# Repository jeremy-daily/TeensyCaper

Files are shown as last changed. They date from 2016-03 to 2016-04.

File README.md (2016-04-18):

# TeensyCaper
Electronics to interface a PRJC Teensy 3.2 32-bit Arduino Compatible board with J1939 connections in heavy duty equipment. Includes Two CAN Channels, J1708, and LIN.

This repository assumes you know how to work with the <a href="https://www.pjrc.com/store/teensy32.html" target="_blank" >Teensy</a> and <a href="https://www.pjrc.com/teensy/teensyduino.html">Teensyduino.</a>

## Bill of Materials

Reference the Schematic for the Designators. Most items are from <a href="http://www.mouser.com" target="_blank" > Mouser </a> or Sparkfun.

| Comment | Description | Designator | Quantity | Manufacturer | Manufacturer Part Number | Supplier | Supplier Part Number |
| --- | --- | --- | --- | --- | --- | --- | --- |
| CR1225FV-LF | Coin Cell Battery 3V 2-PIN VERT 48mAh 12.5 x 2.5mm | Batt1 | 1 | Renata | CR1225FV-LF | Mouser | 614-CR1225FV-LF| 
| Teensy 3.2 | 32 Bit Arduino-Compatible Microcontroller | BRD1 | 1 | <a target="_blank" href="https://www.pjrc.com/store/teensy32.html">PRJC</a> | TEENSY32 | Sparkfun | DEV-13736| 
| 0.1uF | Multilayer Ceramic Capacitors MLCC - Leaded 50volts 0.1uF 10% X7R | C1, C2, C5, C6 | 4 | AVX | SR215C104KAA | Mouser | 581-SR215C104K| 
| 330 uF | Aluminum Electrolytic Capacitors - Leaded 330uF 35V | C3, C4 | 2 | Panasonic | EEU-FC1V331 | Mouser | 667-EEU-FC1V331| 
| 10uF | Multilayer Ceramic Capacitors MLCC - Leaded 50volts 10uF 10% X7R | C7 | 1 | AVX | SR655C106KAR | Mouser | 581-SR655C106KAR| 
| STPS2150 | DIODE SCHOTTKY 60V 2A AXIAL | D1 | 1 | STMicroelectronics | STPS2150 | Mouser | 511-STPS2150| 
| ESP8266 | Sparkfun ESP8266 Module (WRL-13678) | J1 | 1 | Espressif | ESP8266 | Sparkfun | WRL-13678| 
| 10 Pos Mini-Fit Jr. | Headers & Wire Housings 10 CKT R/A HEADER | J2 | 1 | Molex | 39-30-1100 | Mouser | 538-39-30-1100| 
| Headers | Pin headers for Teensy | BRD1 | 2 | 3M  |  929400-01-28-RK | Mouser |  517-929400-01-28-RK| 
| 2N3904 | NPN General Purpose Amplifier | Q1, Q2 | 2 | Central Semiconductor | 2N3904 | Mouser | 610-2N3904| 
| 4.7k | Metal Film Resistors - Through Hole 4.7K OHM 1/4W 1% | R1, R3, R5, R6, R10, R12 | 6 | Yageo | MFR-25FRF52-4K7 | Mouser | 603-MFR-25FRF52-4K7| 
| 47 | Metal Film Resistors - Through Hole 47 OHM 1/4W 1% | R2, R7, R8 | 3 | Yageo | MFR-25FRF52-47R | Mouser | 603-MFR-25FRF52-47R| 
| 1k | Metal Film Resistors - Through Hole 1K ohm 1/4W 1% | R4, R9 | 2 | Yageo | MFR-25FRF52-1K | Mouser | 603-MFR-25FRF521K| 
| MCP2562 | High-Speed CAN Transceiver, 8-Pin PDIP, Industrial Temperature | U1, U2 | 2 | Microchip Technology | MCP2562-E/P | Mouser | 579-MCP2562-E/P| 
| MCP2515-E/P | Stand-Alone CAN Controller With SPI Interface, 18-Pin PDIP | U3 | 1 | Microchip Technology | MCP2515-E/P | Mouser | 579-MCP2515-E/P| 
| MCP2003-E/P | TXRX LIN BUS BIDIRECT 8DIP | U4 | 1 | Microchip Technology | MCP2003-E/P | Mouser | 579-MCP2003EP| 
| SN65HVD12P | RS-485 Interface IC 3.3V RS485 | U6 | 1 | Texas Instruments | SN65HVD12P | Mouser | 595-SN65HVD12P| 
| LD1086V33 | IC REG LDO 3.3V 1.5A TO220AB | VR1 | 1 | STMicroelectronics | LD1086D2M33TR | Mouser | 511-LD1086D2M33-TR| 
| OKI-78SR | 5V DC/DC Converter (7805 replacement) | VR2 | 1 | Murata Power Solutions | OKI-78SR-5/1.5-W36-C | Mouser | 580-OKI78SR5/1.5W36C | 
| Crystal | Crystals 32.768KHz 12ppm 12.5pF | | 1 | Citizen | CFS206-32.768KEZB-U | Mouser | 695-CFS206-327KEZB-U |

Since this is an open source project, feel free to make substitutions as you see fit. Often an engineer or hobbiest will have other version of the parts available to them. 

The Battery and Crystal are for the real time clock on the Teensy. PRJC also sells an SD card adapter to add "flight data recorder" capabilities.

The external interface is with the a 10 position Molex Mini-Fit Jr. and the Molex part numbers to build interface cables are as follows:
* Mouser Part #: 538-39-01-2100
* Molex Part #: 39-01-2100
* Mouser Part #: 538-39-00-0039
* Molex Part #: 39-00-0039

It is advisable to obtain a pin extraction tool for Mini-fit Jr. contacts as well: 
* Mouser Part #: 538-11-03-0044
* Molex Part #: 11-03-0044
Crimpers are also available, but they are expensive (~$250):
* Mouser Part #: 538-63819-0900
* Molex Part #: 63819-0900

The printed circuit board can be ordered from OSH Park in batches of 3 using the following link:



OSH Park sells the Teensy 3.2 too!

### Teensy Headers
The following headers work well with firm inserting force. These are stackable and work for all the expansions boards for the Teensy. They have a long solder tail.
  Mouser Part #: 575-31143164
  Manufacturer Part #:311-43-164-41-001000
  Manufacturer:Mill-Max
  Description: IC & Component Sockets 64 POS STRAIGHT .1"

Additionally, the Mill-Max 310 series is for a base layer (they have standard solder tails).

The following part are dual ended pins that interface with the 311 and 310 series sockets. 
  Mouser Part #: 575-35040132000010
  Manufacturer Part #: 350-40-132-00-001000
  Manufacturer: Mill-Max
  Description: Headers & Wire Housings 32P HDRSTRIP .025Pin .018 SOLDER TAIL
  
## Interface Cables
This section describes some different interface cables than can be made to interface the teensy caper to the networks.
### J1939 at 250k
The black SAE Standard 9-pin connector has the following connections:

| SAE Pin | Description | Suggested Colors | TeensyCaper Pin |
| --- | --- | --- | --- |
| A | Ground | Black | J2:1
| B | Raw Battery + | Red | J2:2
| C | J1939 H | Yellow | J2:3 |
| D | J1939 L | Green | J2:4 |
| E | Shield  | Not used | Not used |
| F | J1708 H | Pink | J2:6 |
| G | J1708 L | Purple | J2:7 |
| H | CAN2 H | White | J2:8 |
| J | CAN2 L | Blue | J2:9 |

Sometimes SAE Pin E can be used for LIN or K-line communications.

The TeensyCaper molex Pin J2:5 is LIN and the pin J2:10 is an open collector that can be switched to ground.

### J1939 Y Splitter Cable
To build a splitter cable, the machined sockets that are used in the diagnostic connector are doubled up. This is not a manuracture approved method of splitting a cable, but it works quite well. 

The parts list is as follows:

|  Description |  Quantity | Manufacturer | Manufacturer Part Number | Supplier | Supplier Part Number |
|  ---|  --- | --- | --- | --- | --- |
| 9-pin Diagnostic Plug Housing | 1 | Amphenol Sine Systems | AHD16-9-1939S | Mouser | 654-AHD16-9-1939S |
| 16 gauge Socket Connector | 9 | Amphenol Sine Systems | AT62-201-16141 | Mouser | 654-AT62-201-16141 |
| 9-pin Inline Receptical | 2 | Amphenol Sine Systems | AHD14-9-1939P | Mouser | 654-AHD14-9-1939P |
| 16 gauge Pin Connector | 18 | Amphenol Sine Systems | AT60-202-16141 | Mouser | 654-AT60-202-16141 |

You will need 18 wires, preferably 2 each of different colors. The wires can be cut to about 8 inches. The side that gets doubled up, it is suggested to strip the ends about 1/2 inch. The other ends get stripped about 1/4 inch. Uing automotive grade 20 gauge wire with TXL or GXL insulation is recommended. Allied Wire and Cable can sell rolls of it; for example, <a target="_blank" href="http://www.awcwire.com/part.aspx?partname=txl-20">TXL-20</a>.

These part numbers also corrospond to Deutsch part numbers by changing the A to a D.

### Man-in-the-Middle Cable
This cable connects to one J1939 connector with a plug housing on CAN1 of the TeensyCaper and another receptical housing to J1939 on CAN2.
The CAN 2 cavities are not used on the 9-pin connector. Power, ground, and J1708 are doubled up on the plug housing. 

## SD Card
### 

Add the following lines to the beginning of the setup() function:
 
  pinMode(SDCS, OUTPUT);
  digitalWrite(SDCS, HIGH);   // de-select the SD Card

  where SDCS is the chip select pin for the SD card.
  
  The SD Card holder from PJRC will not work with the CAN because it uses Pin 4. Therefore, you must cut the pin 4 off the SD card holder and connect it somewhere else, like pin A1.

##Arduino
1. Download Teensyduino with FlexCAN
2. Install library for SD cards from https://github.com/greiman/SdFat-beta

#Software Operations
The philosophy of this setup is to run different operations by using different example sketches. 

##Formatting the SD Card
With an SD card installed in the SD card expansion shield for Teensy ()

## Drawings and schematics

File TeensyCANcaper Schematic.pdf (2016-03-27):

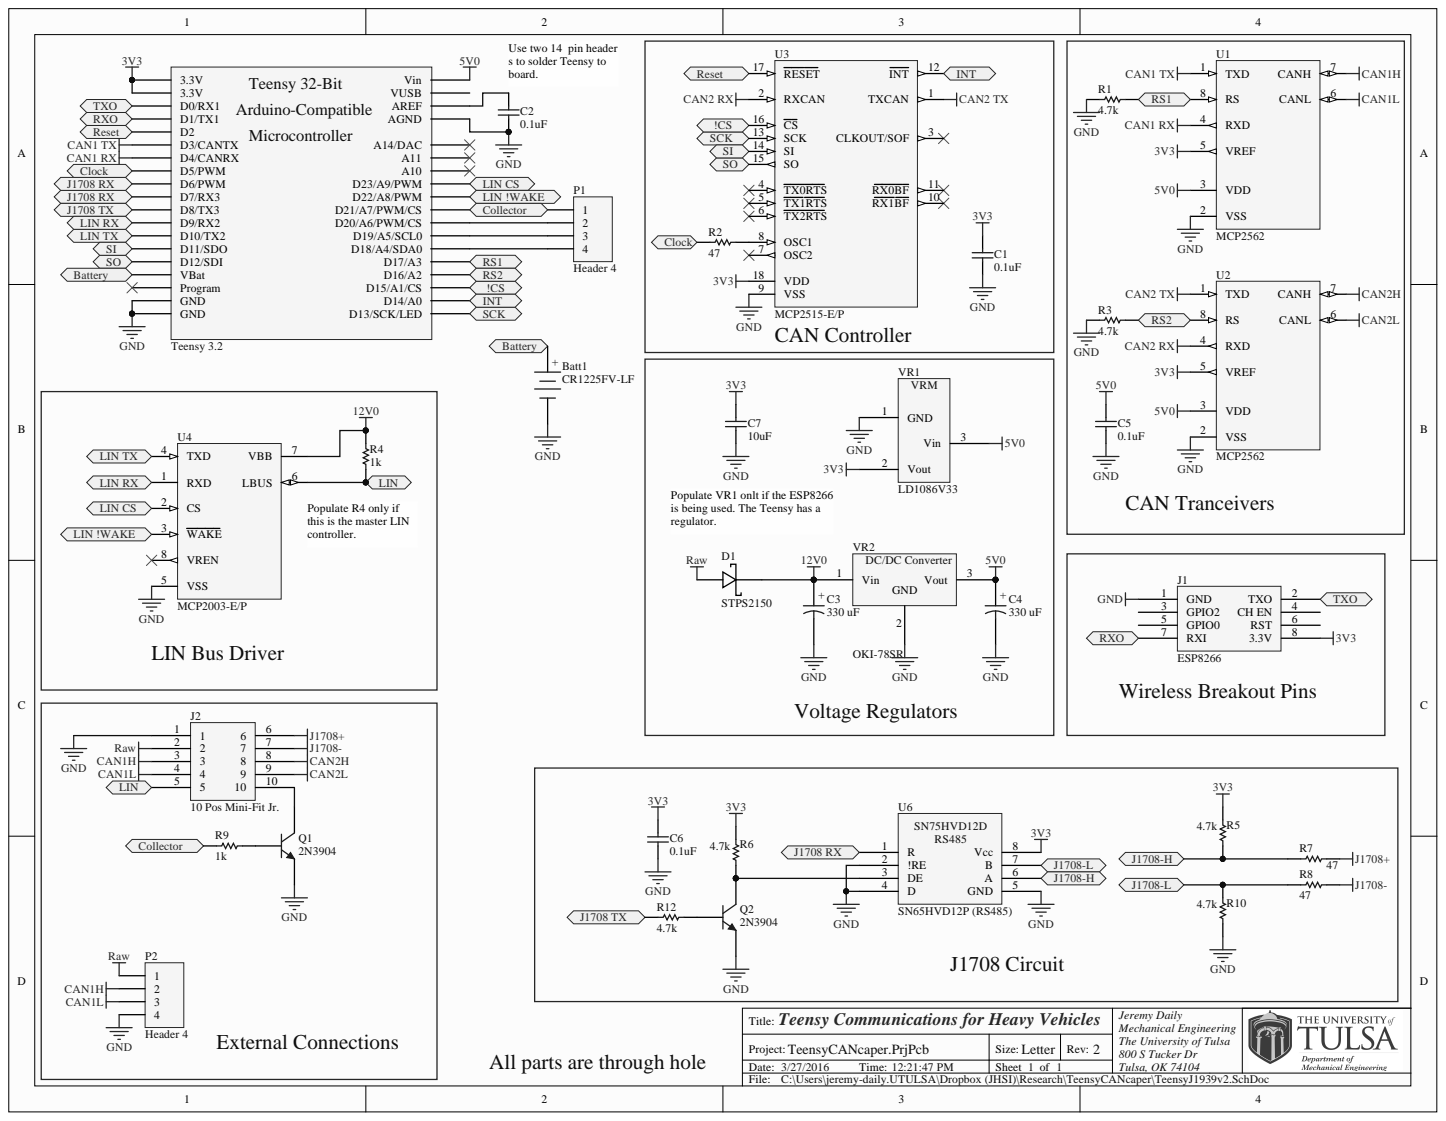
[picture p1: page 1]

Use two 14 pin header
s to solder Teensy to
board.

Populate R4 only if
this is the master LIN
controller.

Populate VR1 onlt if the ESP8266
is being used. The Teensy has a
regulator.

10 Pos Mini-Fit Jr.

Teensy Communications for Heavy Vehicles
Title:

Jeremy Daily
Mechanical Engineering
The University of Tulsa
800 S Tucker Dr

C:\Users\jeremy-daily.UTULSA\Dropbox (JHSI)\Research\TeensyCANcaper\TeensyJ1939v2.SchDoc

All parts are through hole

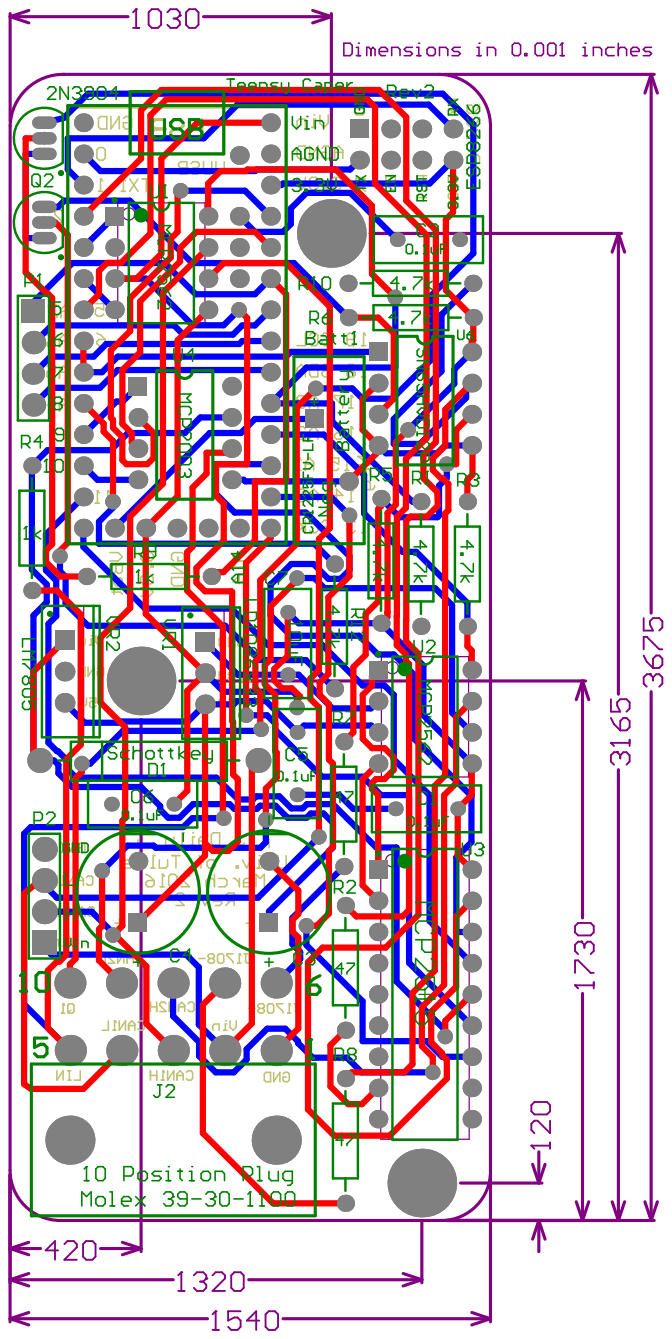
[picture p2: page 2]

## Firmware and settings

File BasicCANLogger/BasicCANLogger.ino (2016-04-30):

/* Getting Started with the J1939 Teensy Caper
Written By Jeremy Daily
17 April 2016

This System is written for a Teensy3.2 with an SD board and the TeensyJ1939Caper 
Needs to cut pin4 from the SD card

Description: A Basic CAN logger

*/

#include <SPI.h>
#include "SdFat.h"
//#include "FreeStack.h"

#include <FlexCAN.h>

// SD chip select pin.  Be sure to disable any other SPI devices such as Enet.
const uint8_t SDchipSelect = 10;
const uint8_t CANchipSelect = A1;

// Log file base name.  Must be six characters or less.
#define CANFILE_BASE_NAME "CANlog"
#define J1708FILE_BASE_NAME "J1708log"

// global for card size
uint32_t cardSize;

const int CANRate = 250000;

FlexCAN CANbus(CANRate);

static CAN_message_t txCANmsg,rxCANmsg;

uint32_t txCANcount,rxCANcount;
uint32_t txCANtimer,rxCANtimer;
uint32_t currentMillis,previousMillis;
boolean recording = true;

// File system object.
SdFat sd;

// Log file.
SdFile CANfile;


// Time in micros for next data record.
uint32_t logTime;

// Write data header.
void writeHeader() {
  CANfile.println(F("CAN Data Log"));
  CANfile.print(F("Rate,"));
  CANfile.println(CANRate, DEC);
  CANfile.print(F("Network,"));
  CANfile.print(F("Micros,"));
  CANfile.print(F("Line,"));
  CANfile.print(F("ID,"));
  CANfile.print(F("DLC,"));
  CANfile.print(F("B0,"));
  CANfile.print(F("B1,"));
  CANfile.print(F("B2,"));
  CANfile.print(F("B3,"));
  CANfile.print(F("B4,"));
  CANfile.print(F("B5,"));
  CANfile.print(F("B6,"));
  CANfile.print(F("B7,"));
  CANfile.println();
}
void logCANframe(){
  uint32_t currentMicros = micros();
  CANfile.print("CAN");
  CANfile.print(",");
  CANfile.print(currentMicros,DEC);
  CANfile.print(",");
  CANfile.print(rxCANcount);
  CANfile.print(",");
  CANfile.print(rxCANmsg.id,HEX);
  CANfile.print(",");
  CANfile.print(rxCANmsg.len,DEC);
  CANfile.print(",");
  for( int idx=0; idx<rxCANmsg.len; ++idx ) {
      CANfile.print(rxCANmsg.buf[idx],HEX);
      CANfile.print(",");
  
    }
  CANfile.println();
  rxCANcount++;
}
void logJ1708byte(){
  uint32_t currentMicros = micros();
  uint8_t c = Serial3.read();
  CANfile.print("J1708");
  CANfile.print(",");
  CANfile.print(currentMicros,DEC);
  CANfile.print(",");
  CANfile.println(c,HEX);
  
}

void setup()
{
  
  pinMode(SDchipSelect, OUTPUT);
  digitalWrite(SDchipSelect, HIGH);   // de-select the SD Card
  pinMode(CANchipSelect, OUTPUT);
  digitalWrite(CANchipSelect, HIGH);   // de-select the SD Card
  pinMode(13,OUTPUT);
  digitalWrite(13,HIGH); //turn on LED
  pinMode(0,INPUT_PULLUP);
  
  Serial.begin(115200);
  delay(1000);
  
  Serial.println("Starting CAN Logger");
  while (!sd.begin(SDchipSelect, SPI_FULL_SPEED)) {
    delay(100);
    Serial.println("Error with SD Card.");
  }
 
  Serial.print("\nInitializing SD card...");


  // we'll use the initialization code from the utility libraries
  // since we're just testing if the card is working!
  if (!sd.cardBegin(SDchipSelect, SPI_FULL_SPEED)) {
    Serial.println("initialization failed. Things to check:");
    Serial.println("* is a card inserted?");
    Serial.println("* is your wiring correct?");
    Serial.println("* did you change the chipSelect pin to match your shield or module?");
    return;
  } else {
   Serial.println("Wiring is correct and a card is present."); 
  }

  cardSize = sd.card()->cardSize();
  // print the type of card
    switch (sd.card()->type()) {
  case SD_CARD_TYPE_SD1:
    Serial.print("SD1\n");
    break;

  case SD_CARD_TYPE_SD2:
    Serial.print("SD2\n");
    break;

  case SD_CARD_TYPE_SDHC:
    if (cardSize < 70000000) {
      Serial.print("SDHC\n");
    } else {
      Serial.print("SDXC\n");
    }
    break;

  default:
    Serial.print("Unknown\n");
  }

 

 
 
  
  Serial.println("Starting CAN Bus");
  CANbus.begin();
  Serial3.begin(9600);
  
}


void logData(){
  const uint8_t BASE_NAME_SIZE = sizeof(CANFILE_BASE_NAME) - 1;
  
  char fileName[13] = CANFILE_BASE_NAME "00.csv";
   // Find an unused file name.
  if (BASE_NAME_SIZE > 6) {
    Serial.println("FILE_BASE_NAME too long");
  }
  while (sd.exists(fileName)) {
    if (fileName[BASE_NAME_SIZE + 1] != '9') {
      fileName[BASE_NAME_SIZE + 1]++;
    } else if (fileName[BASE_NAME_SIZE] != '9') {
      fileName[BASE_NAME_SIZE + 1] = '0';
      fileName[BASE_NAME_SIZE]++;
    } else {
      Serial.println("Can't create file name. Overwriting.");
      break;
    }
  }
  
  recording = digitalRead(0);
  if (recording){
      delay(150);
      recording = digitalRead(0);    
      if (recording){
          if (!CANfile.open(fileName, O_CREAT | O_WRITE | O_APPEND)) {
              Serial.println("file.open error!");
              return;
          }
          Serial.print(F("Logging data to: "));
          Serial.println(fileName);
          writeHeader();
          
          while (recording) {
            recording = digitalRead(0);
            if (Serial3.available()) logJ1708byte();
            while (CANbus.read(rxCANmsg)) logCANframe();
  
            currentMillis = millis();
            if (currentMillis - previousMillis >= 1000){
              previousMillis = currentMillis;
              Serial.println(rxCANcount);
            }
          }
          
          CANfile.close();
          delay(1000);
          digitalWrite(13,HIGH);
          delay(1000);
          digitalWrite(13,LOW);
          rxCANcount = 0;
        }
     }
    
}

void loop(){
  logData();
  
}

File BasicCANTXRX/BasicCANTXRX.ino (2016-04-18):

/* Getting Started with the J1939 Teensy Caper
Written By Jeremy Daily
17 April 2016

This System is written for a Teensy3.2 with an SD board and the TeensyJ1939Caper

Description: A Basic CAN logger
*/
#include <FlexCAN.h>

const int CANRate = 500000;

FlexCAN CANbus(500000);
static CAN_message_t txCANmsg,rxCANmsg;

uint32_t txCANcount,rxCANcount;
uint32_t txCANtimer,rxCANtimer;
uint32_t currentMillis,previousMillis;

void setup()
{
  
 // pinMode(SDchipSelect, OUTPUT);
 // digitalWrite(SDchipSelect, HIGH);   // de-select the SD Card
 
  Serial.begin(115200);
  while (!Serial) {
    ; // wait for serial port to connect. Needed for Leonardo only
  }
  
  
  Serial.println("Starting CAN Bus");
  CANbus.begin();
  
  
 
}

void loop(){
  currentMillis = millis();
  
  while ( CANbus.read(rxCANmsg) ) {
      Serial.write(rxCANmsg.buf[0]);
      rxCANtimer=micros();
      rxCANcount++;
      logCANframe();
  }
  if (currentMillis - previousMillis >= 100){
    previousMillis = currentMillis;
    Serial.println(rxCANcount);
    txCANmsg.buf[0]= (currentMillis & 0xFF000000) >> 24;
    txCANmsg.buf[1]= (currentMillis & 0x00FF0000) >> 16;
    txCANmsg.buf[2]= (currentMillis & 0x0000FF00) >>  8;
    txCANmsg.buf[3]= (currentMillis & 0x000000FF);
    CANbus.write(txCANmsg);
    txCANcount++;
  }
}

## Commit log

2016-03-27 Uploaded Schematic, Altium files and Gerber files.
    Included a link to OSH Park boards and expanded the README.md file to
    include a bill of materials.
    [TeensyCANcaper.PrjPcb, TeensyJ1939v2.PcbDoc, TeensyJ1939v2.SchDoc]
2016-03-27 Updated Bill of materials
    Added interface cable part numbers and table formats.
2016-03-27 Added wiring harness definitions
    Splitter cable and Man-in-the-middle.
2016-04-18 Initial Attempts at getting CAN to SD
    Still need to test, since SD shield is incompatible with CAN (Pin 4).
    [BasicCANLogger.ino, BasicCANTXRX.ino]
